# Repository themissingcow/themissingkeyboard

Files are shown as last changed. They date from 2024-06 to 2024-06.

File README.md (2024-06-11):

# The Missing Keyboard

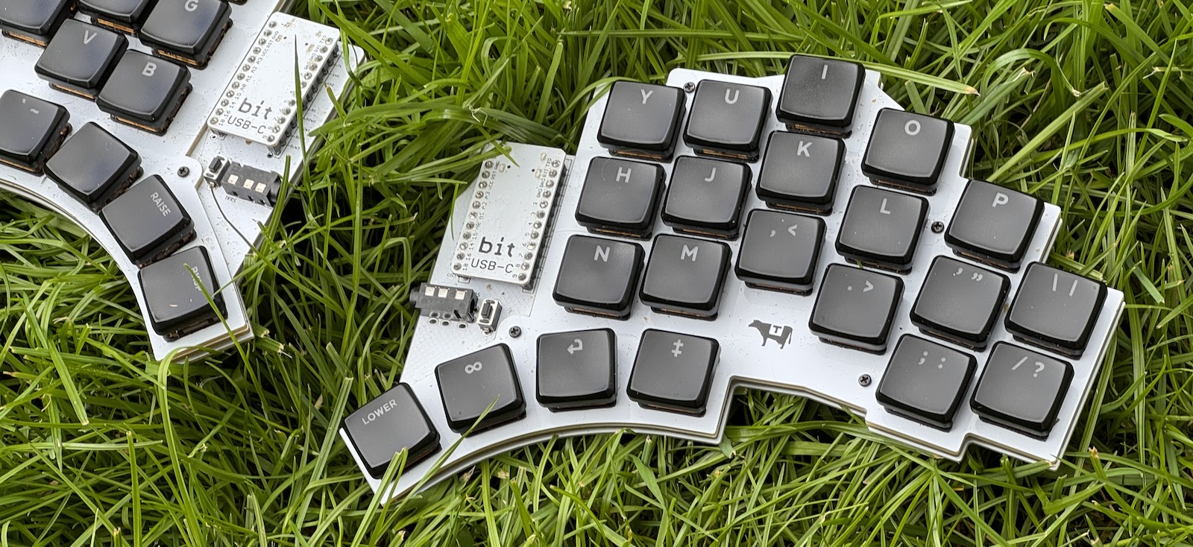
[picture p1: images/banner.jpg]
The Missing Keyboards


A minimal, opinionated, column-staggered 42 key split keyboard based on
the [KLOR](https://github.com/GEIGEIGEIST/KLOR).

- QMK firmware with developer-focused QWERTY and COLMAK layouts.
- Home row mods.
- Per-key RGB matrix.
- Minimal 3-board construction.
- Choc v1 hotswap (or soldered KS-27[^1])

It has the same staggered key layout as KLOR, but with a smaller
footprint.

## Extra Layers

- LOWER Numeric keypad.
- UPPER Shifted top-row numbers, arrows and brackets.
- LOWER + UPPER Switch layout.

## Parts

Aside from the PCBs, you'll most likely need:

- 42 Choc v1 hotswap (or KS-27*) sockets + key switches.
- 2x [ProMicro ATmega32U4 or compatible MCUs[^2] (machine pin sockets
  recommended).
- 42x SK6812 Mini LED (not Mini-E) 3535 size.
- 2x PTS636 reset switches.
- 2x TRRS 3.5mm jack sockets (MJ-4PP-9 or PJ320A).
- 1x TRRS cable.
- 8x M2 Standoffs (4mm for choc).
- 8x M2 screws (3mm for choc).
- 8x Sticky feet.

> Note:
> This is my first build, so please double-check parts and quantities
> before ordering in case I messed anything up!

## Build

You should hopefully be able to follow the original KLOR [Build
Guide](https://github.com/GEIGEIGEIST/KLOR/blob/main/docs/buildguide_3DP.md),
omitting the removed components.

The main difference is that with the stacked PCB build, you'll probably
want to mount the MCUs **upside down** on the **top** of the board (see
picture). Especially if you're socketing it.

### Assembly

Once the main board is fully soldered, stack the switch plate on
top, and push the key switches through into the sockets on the
back of the main board. You can then screw the stand-offs to this,
before putting the backplate PCB on the bottom.

## Thanks

Many thanks to [@GEIGEIGEIST](https://github.com/GEIGEIGEIST/KLOR) for
the original design, and
[@sadekbaroudi](https://github.com/sadekbaroudi/KLOR) for the choc
version.

----
[^1]: I've only ever built this with chocs.
[^2]: [Nullbits](https://nullbits.co/bit-c/) make some great MCUs.

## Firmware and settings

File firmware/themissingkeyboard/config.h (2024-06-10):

/*
 * Copyright 2022 GEIST @geigeigeist
 * Copyright 2023 Tom Cowland
 *
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
 * You should have received a copy of the GNU General Public License
 * along with this program.  If not, see <http://www.gnu.org/licenses/>.
 */

#pragma once
// Key matrix configuration

#define DIODE_DIRECTION COL2ROW
#define MATRIX_ROW_PINS { C6, D7, E6, B4 }
#define MATRIX_COL_PINS { F6, F7, B1, B3, B2, B6 }
#define MATRIX_ROWS 8  // Split doubles rows
#define MATRIX_COLS 6
#define DEBOUNCE 5

// Split comms

#define USE_SERIAL
#define SOFT_SERIAL_PIN D2
#define SERIAL_USE_MULTI_TRANSACTION
#define SPLIT_TRANSPORT_MIRROR

// Bit-c MCUs
#define DISABLE_BITC_LED

// Key LEDs (RGB)

#define WS2812_DI_PIN D3
#define RGB_DISABLE_WHEN_USB_SUSPENDED

#ifdef RGBLIGHT_ENABLE
#define RGBLIGHT_SLEEP
#define RGBLIGHT_SPLIT
#define DRIVER_LED_TOTAL 42
#define RGBLED_NUM 42
#define RGBLED_SPLIT { 21, 21 }
#endif

#ifdef RGB_MATRIX_ENABLE
#define RGB_MATRIX_LED_COUNT 42
#define RGB_MATRIX_SPLIT { 21, 21 }
#endif

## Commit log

2024-06-10 Add KiCAD PCB files
    [tmk_backplate.kicad_pcb, tmk_switchplate.kicad_pcb]
2024-06-11 Switch to footnotes in README

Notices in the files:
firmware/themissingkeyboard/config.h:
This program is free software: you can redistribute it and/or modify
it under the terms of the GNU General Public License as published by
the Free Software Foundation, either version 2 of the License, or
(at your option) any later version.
